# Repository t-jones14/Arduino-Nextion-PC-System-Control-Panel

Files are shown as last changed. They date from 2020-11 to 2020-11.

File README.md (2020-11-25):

<p align="center">






</p>

<p align="center">
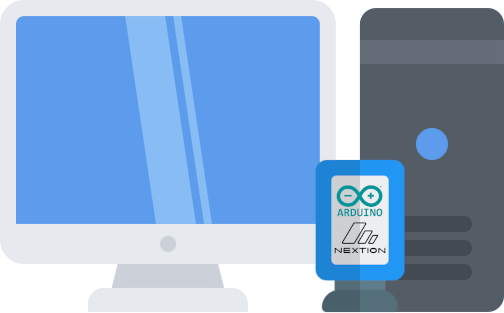
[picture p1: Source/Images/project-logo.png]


<h3 align="center">Arduino &amp; Nextion PC System Control Panel
</h3><br>
<br>
<p align="center">
An external PC system control panel built with Arduino Nano and Nextion Display<br>
<a align="center" href="https://t-jones14.github.io/Arduino-Nextion-PC-System-Control-Panel/">Explore the docs »</a><br>
<a align="center" href="https://github.com/t-jones14/Arduino-Nextion-PC-System-Control-Panel/issues">Report Bug »</a><br>
<a align="center" href="https://github.com/t-jones14/Arduino-Nextion-PC-System-Control-Panel/issues">Request Feature »</a>
</p>
</p>

<br>

## About The Project
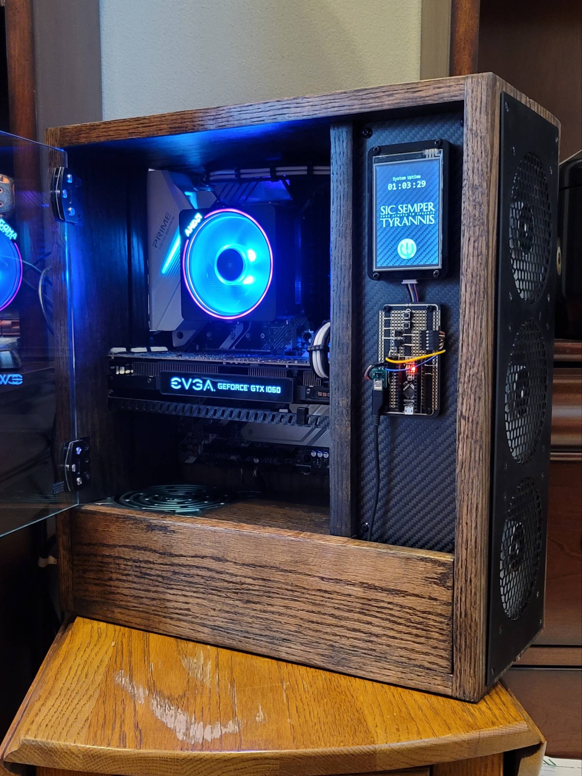
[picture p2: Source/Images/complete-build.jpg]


This project started when I decided to build a computer. Having never built one before, I decided to go all-out (kind of). I wanted it to be unique and highlight my abilities. Throughout the design and construction phase I entirely neglected to incorporate any system controls and decided to get creative. To stick with the "exposed" theme of the build the idea to incorporate a raw, yet-modern approach was born.

<a href="https://github.com/t-jones14/Arduino-Nextion-PC-System-Control-Panel">Finished Project</a>

### Built With

* Arduino Nano V3.0 (Elegoo Nano V3.0+) w/ ATmega328P: <a href="https://www.amazon.com/gp/product/B07TTN2HMQ">Amazon</a>
* Nextion Enhanced 3.5" HMI Resistive Touchscreen: <a href="https://www.amazon.com/gp/product/B08535V3KW">Amazon</a>

## Getting Started

Overall, this project is rather simple... If you're somewhat semi-technically inclined.

I highly encourage you to do your research and not take on any task you're not 110% comfortable with. As a reminder, this project is provided AS-IS with ZERO WARRANTY in any way, shape, or form. You're on your own. If you fry your motherboard, that's on you.

The saying goes: "*Measure twice, cut once.*" - Abide by it.

### Here's What You Will Need

Links to all used components included. I am not receiving any commissions if you use any of the links below.

* General Electronics Experience (Highly Recommended)
* Various Electronics Components
    * X3 Schottky Diodes: <a href="https://www.amazon.com/gp/product/B07YG8K1R9">Amazon</a>
    * X2 LED: <a href="https://www.amazon.com/gp/product/B01C19ENDM">Amazon</a>
    * X2 Pushbuttons: <a href="https://www.amazon.com/gp/product/B01CGMP9GY">Amazon</a>
    * X4 Resistors: <a href="https://www.amazon.com/gp/product/B07BKVNBH6">Amazon</a>
    * X2 BC548 Power Transistors: <a href="https://www.amazon.com/gp/product/B071P849QB">Amazon</a>
    * 2.54mm Pitch Dupont Connectors: <a href="https://www.amazon.com/gp/product/B07D91MQQ8">Amazon</a>
    * Wire Strippers: <a href="https://www.amazon.com/gp/product/B07GJFVXXD">Amazon</a>
    * Wire Crimp Tool: <a href="https://www.amazon.com/gp/product/B01CE4FAMW/">Amazon</a>
    * Soldering Iron: <a href="https://www.amazon.com/gp/product/B07SCPZJYS">Amazon</a>
    * X1 Blank Prototyping PCB: <a href="https://www.amazon.com/gp/product/B07ZYNWJ1S">Amazon</a>
    * X1 Breadboard: <a href="https://www.amazon.com/gp/product/B07DL13RZH">Amazon</a>
    * Jumper Wires: <a href="https://www.amazon.com/gp/product/B01EV70C78">Amazon</a>
* Arduino IDE: <a href="https://www.arduino.cc/en/software">Link</a>
* Nextion Editor: <a href="https://nextion.tech/nextion-editor/">Link</a>
* A motherboard with front-panel system control headers for a powerswitch, reset switch, +5V & Ground connection

## Wiring Schematic

#### A Few Notes Regarding the Schematic

1. JP1 & JP2 are to disconnect the RX/TX pins from the Arduino Nano in order to be able to upload code to the Nano without removing it from the PCB. If you leave these connected or forego the jumpers, you will not be able to upload any code to the Arduino if the Nextion is connected since the RX and TX pins are used when the board is communicating via USB.
2. J1 Pin 1 MUST be a constant +5V to power the board and display. I have my BIOS set to always supply +5 to USB so I just ran a USB from an available USB header off the motherboard.
3. J2 Pin 4 must be +5V from the motherboard ONLY when the MB is alive. I used the +5V on the System Panel Connector header for the System Warning Speaker. See below.
4. You can forego the LEDs and Pushbuttons. I opted for them for extra effect and as a backup in case the Nextion display ever stopped working before I could replace it. Better to be over-prepared than under-prepared.
5. J1 are male headers for connection to the Nextion display.
6. J2 are male headers for the wiring from the motherboard front-panel system control headers.
7. If you're using LED's from your motherboard's LED connections, ensure they are regulated. If on the off-chance they are not, you will need to integrate resistors in-series prior to the LED's.

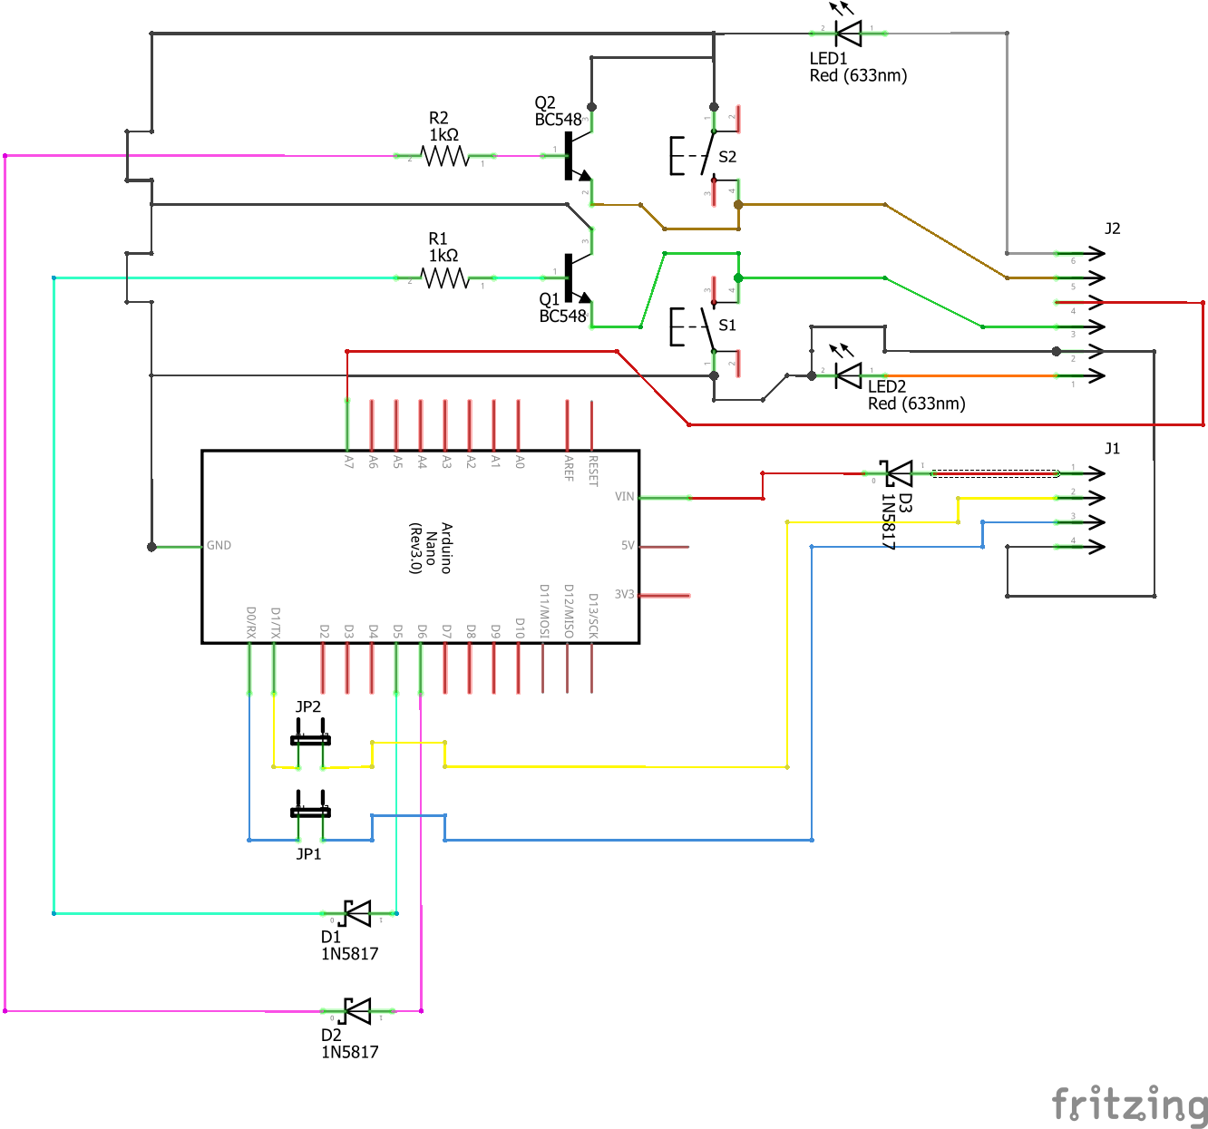
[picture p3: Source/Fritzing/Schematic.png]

Image: Wiring Schematic

For the Fritzing file <a href="https://github.com/t-jones14/Arduino-Nextion-PC-System-Control-Panel/blob/main/Source/Fritzing/Schematic.fzz">click here</a>.

## Breadboard Prototype / Bench Test

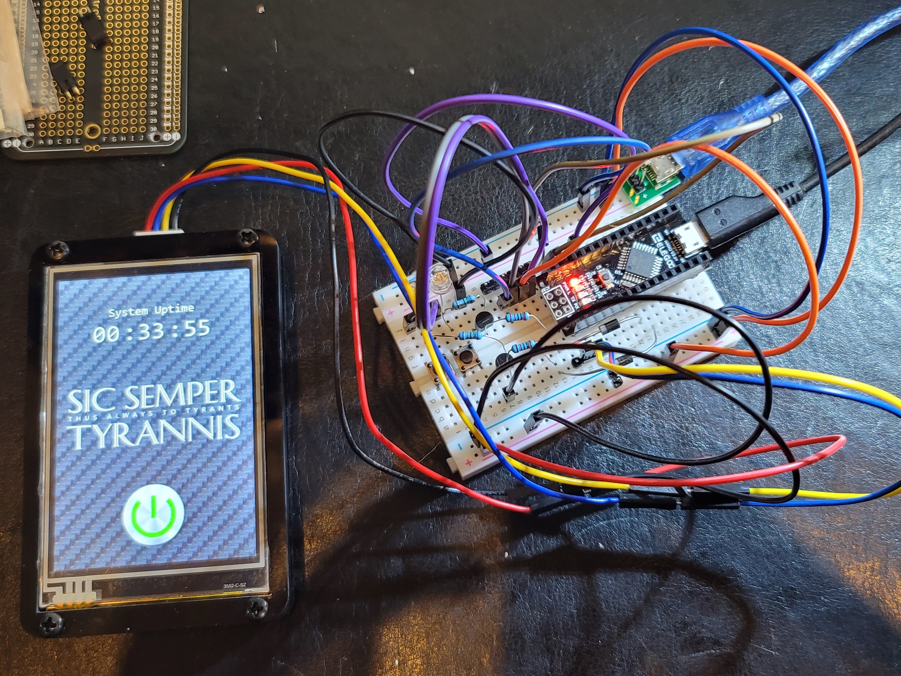
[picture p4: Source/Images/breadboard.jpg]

Image: Breadboard Prototype


Image: Final PCB Prototype

## Motherboard Wiring

Please reference your motherboard's user manual or contact your motherboard manufacturer to confirm wiring / operation. Again, this software and hardware is provided **AS-IS** with **NO WARRANTY** expressed or implied. I **am not** responsible if you fry your motherboard. Please DO NOT continue if you're not confident in your abilities. I cannot tell you how many times I confirmed details and reconfirmed before attaching any wires up to my $250 motherboard.

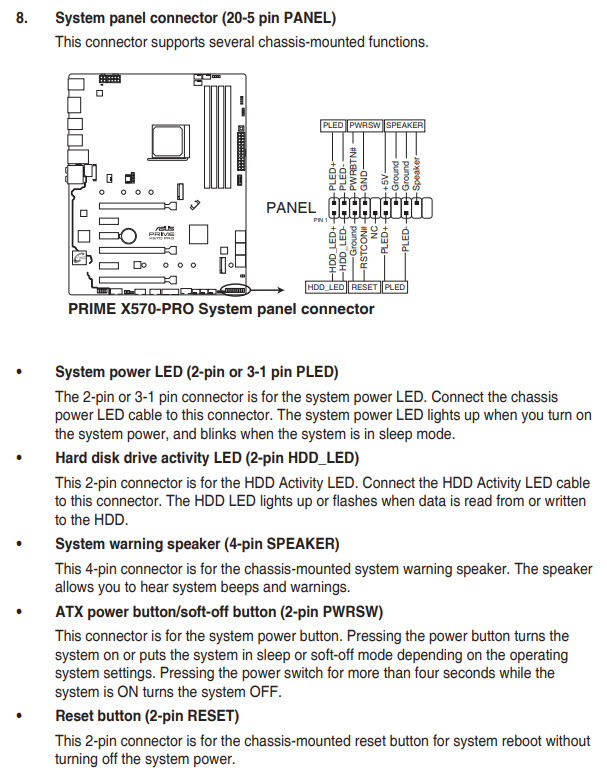
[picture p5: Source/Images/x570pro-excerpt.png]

Image: ASUS Prime X570-Pro User Manual Excerpt
Link: <a href="https://dlcdnets.asus.com/pub/ASUS/mb/SocketAM4/PRIME_X570-PRO/E17432_PRIME_X570-PRO_UM_v3_web.pdf">Asus Prime X570-Pro User Manual</a>


Image: Motherboard System Panel Connection Headers

## Roadmap

See the [open issues](https://github.com/t-jones14/Arduino-Nextion-PC-System-Control-Panel/issues) for a list of proposed features (and known issues).

## Contributing

Contributions are what make the open source community such an amazing place to be learn, inspire, and create. Any contributions you make are **greatly appreciated**.

1. Fork the Project
2. Create your Feature Branch (`git checkout -b feature/AmazingFeature`)
3. Commit your Changes (`git commit -m 'Add some AmazingFeature'`)
4. Push to the Branch (`git push origin feature/AmazingFeature`)
5. Open a Pull Request

## License

Distributed under the GNU General Public License V3.0. See `LICENSE` for more information.

## Contact

Taylor Jones - taylor@nexgendms.com

Project Link: [https://github.com/github/t-jones14/Arduino-Nextion-PC-System-Control-Panel](https://github.com/t-jones14/Arduino-Nextion-PC-System-Control-Panel)

## Acknowledgements

* [Read Me Template by othneildrew](https://github.com/othneildrew/Best-README-Template)

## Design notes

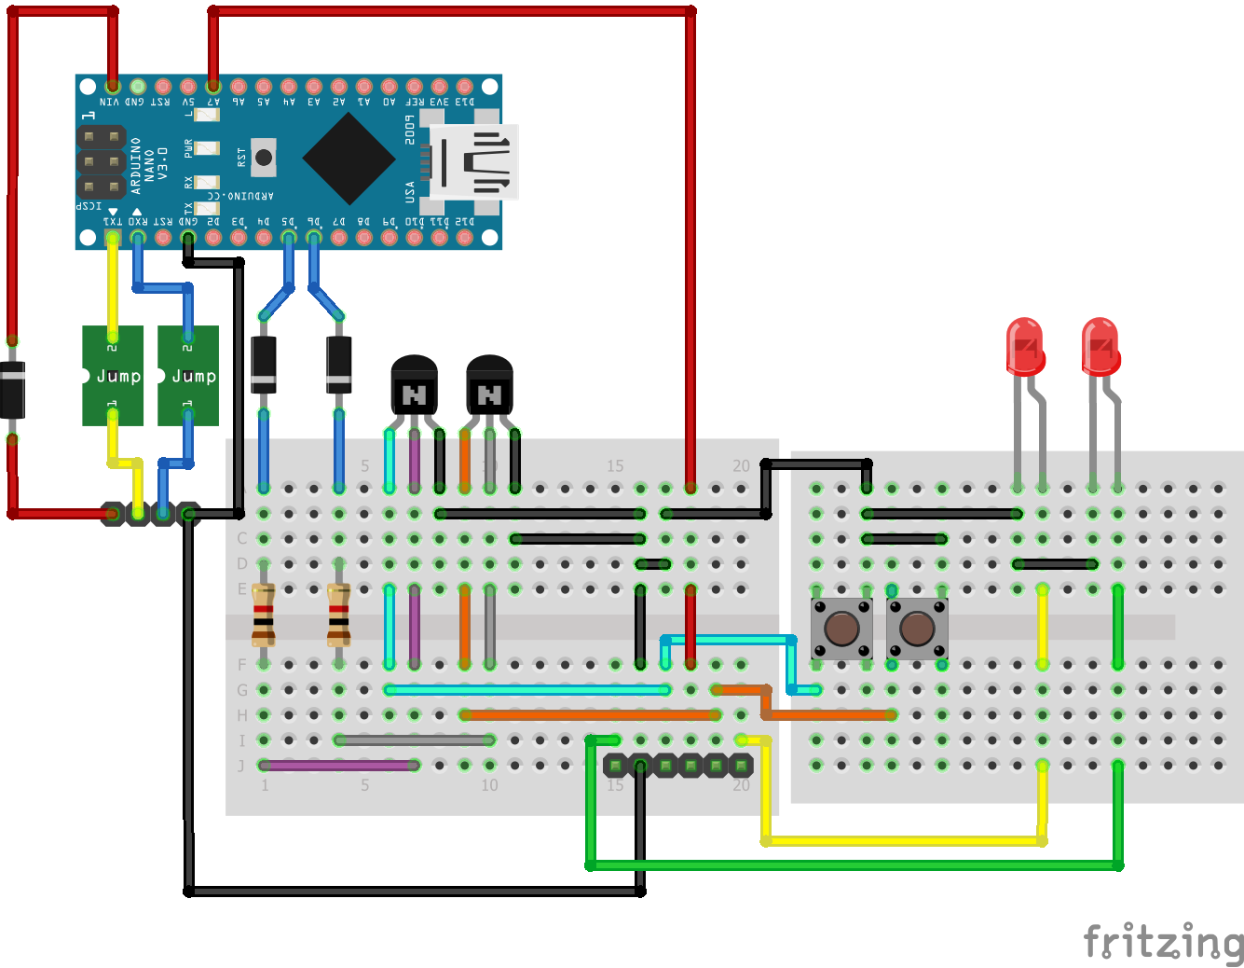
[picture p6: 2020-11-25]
Source/Fritzing/Schematic_bb.png

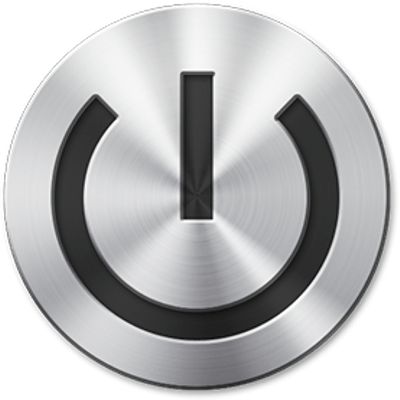
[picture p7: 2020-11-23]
Source/Images/pwrBtn-dark.png

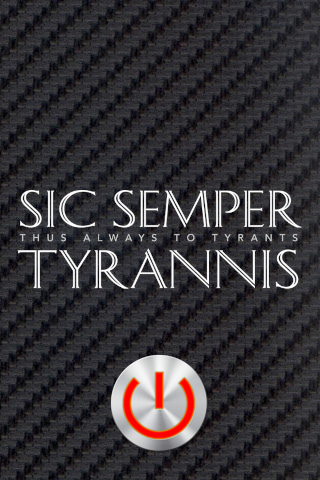
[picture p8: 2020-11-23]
Source/Images/bg-cf-sst-pwr-off.png

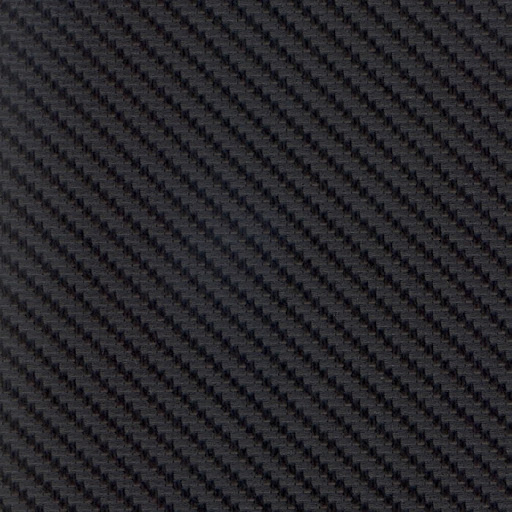
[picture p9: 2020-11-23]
Source/Images/carbonFiber.jpg

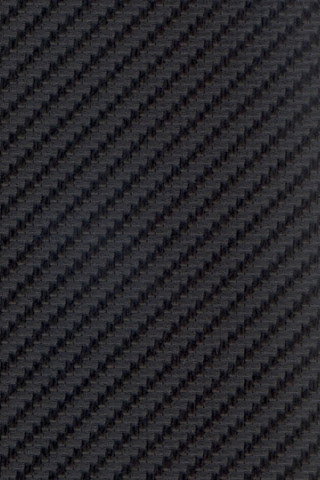
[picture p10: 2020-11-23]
Source/Images/carbonFiber-320x480.png

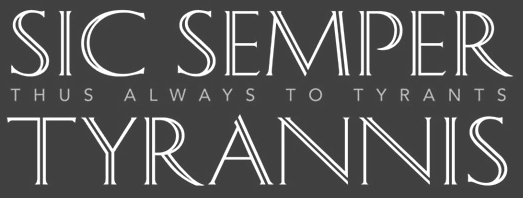
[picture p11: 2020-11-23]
Source/Images/SIC-SEMPER-TYRANNIS.png

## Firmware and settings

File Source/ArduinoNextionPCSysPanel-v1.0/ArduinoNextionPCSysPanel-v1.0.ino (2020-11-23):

/*  Arduino & Nextion PC System Control Panel
 *  Copyright (C) 2020  by Taylor Jones / www.github.com/t-jones14

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
*/

#include <EasyNextionLibrary.h> // include library
#include <trigger.h>            // include library

EasyNex myNex(Serial);          // Create an object of EasyNex class

// CUSTOMIZABLE VARIABLES
const int POWER_SW = 5;         // BJT1 - Check Schematic
const int RESET_SW = 6;         // BJT2 - Check Schematic
const int MB_CHECK = A7;        // +5V From Motherboard System Panel Connector

const int FORCE_TIME = 4000;     // Amount of time to hold POWER_SW closed to force system shutdown
// NOTE: Consult your motherboard user manual for the time required for forced shutdown.

// FIXED VARIABLES
// Do not edit these unless you know what you're doing.
// ====================================================
// State Management Variables
int mbState = 0;                  // This variable will hold the state of the motherboard. 0:Off/1:On
int interval = 1000;              // Rate (in millis) to run our custom loop

// Time Variables
unsigned long refresh_timer = millis();  // timer for refreshing Nextion's page
long currentMillis = millis();           // This will store the current time
unsigned long previousMillis = 0; // This will store the last time we looped
long sysStartTime = 0;            // This will store the time (in millis) when the MB was powered on
// TODO: long sysStopTime = 0;    // NOT IMPLEMENTED: This will store the time (in millis) when the MB was powered off last
long currentUptime = (sysStartTime - currentMillis);  // This will store our current system uptime
String rUptime = "";              // This var holds the readable uptime thats written to nextion display

//Nextion Variables to Write
String vHr = "";                  // Hours
String vMin = "";                 // Minutes
String vSec = "";                 // Seconds

// setup() runs when the Arduino is powered on or software reset (RST)
void setup() {

  myNex.begin(9600); // Begin serial communication with Nextion

  // Set the Output and Input pins
  pinMode(POWER_SW, OUTPUT);
  pinMode(RESET_SW, OUTPUT);
  pinMode(MB_CHECK, INPUT);

  // When the arduino is first powered on we need to figure out what state we need to be in.
  // We will accomplish this by first checking if the motherboard is powered on or not.
  float mbVoltage = getMbVoltage(); // get motherboard voltage via getMbVoltage() helper function

  // Now, let's get the current page Nextion is showing
  int currentPage = getCurrentPage();

  // if motherboard voltage is greater-than 1V
  if (mbVoltage > 1) {
    mbState = 1;              // set the motherboard state to 1:ON
    sysStartTime = millis();   // set the system start time
    if (currentPage != 1) {

      myNex.writeStr("page 1"); // Since motherboard is on, go to page 1
      loop();  // Now our arduino and nextion are in-sync and on the proper pages. Let's head to the loop();

    }
  } else {
    mbState = 0; // set the motherboard state to 0:OFF
    if (currentPage != 0) {
      myNex.writeStr("page 0"); // Since motherboard is off, go to page 0
      loop();  // Now our arduino and nextion are in-sync and on the proper pages. Let's head to the loop();
    }
  }

}

void loop() {

  // Our loop is pretty simple... we just need to listen for trigger events from the display
  // and write the system uptime to the display if the system is powered on.

  // lets start by checking what state we're in
  // lets get the current page just to make sure we're in-sync
  int currentPage = getCurrentPage();
  if (mbState == 1 && currentPage == 1) {
    // we're going to use a built-in "delay" so we're not sending needless writes to the nextion display
    if ((millis() - refresh_timer) > interval) {
      // since the motherboard is on and we're on page1 lets update the displayed uptime
      getUptime(); // update our time variables
      myNex.writeStr("tHr.txt", vHr); // write system hours uptime
      myNex.writeStr("tMin.txt", vMin); // write system minutes uptime
      myNex.writeStr("tSec.txt", vSec); // write system seconds uptime
      refresh_timer = millis();  // Set the timer equal to millis, create a time stamp to start over the "delay"
    }
  } else if (mbState == 1 && currentPage == 0) {

    // since motherboard is on, but we're on page0 lets get to page1
    // NOTE: currentPage!=1 is not used here because of page2 (shutdown options)
    myNex.writeStr("page 1"); // force page1

  }
  myNex.NextionListen(); // This function listens for Nextion events
}

// When the "page3 > Normal" OR "page0 > Power" option is selected
void trigger1() {

  int currentPage = getCurrentPage(); // get the current page Nextion is displaying

  // lets figure out which page we're on so we can perform the proper sequence
  if (currentPage == 0) {
    // since we're on page0 that means the system is off and we're booting it up
    sysStartTime = millis(); // set the system start time
    mbState = 1; // set mbState to 1 since we're turning on the PC
  } else if (currentPage == 2) {
    // since we're on page 2 (shutdown options)
    mbState = 0; // set mbState to 0 since we're turning off the PC
    myNex.writeStr("tHr.txt", "00"); // write system hours to 00
    myNex.writeStr("tMin.txt", "00"); // write system minutes to 00
    myNex.writeStr("tSec.txt", "00"); // write system seconds to 00
    //TO-DO:  Implement last total uptime
  }

  // trigger the switch
  digitalWrite(POWER_SW, HIGH);   // apply voltage to the BJT Base
  delay(500);                     // keep switch closed for 1/2 second
  digitalWrite(POWER_SW, LOW);    // Remove voltage from the BJT Base
}

// When the "page3 > Force" option is selected
void trigger2() {
  // trigger the switch
  digitalWrite(POWER_SW, HIGH);   // apply voltage to the BJT Base
  delay(FORCE_TIME);              // how long to hold closed for forced shutdown
  mbState = 0;                    // set mbState to 0 since we're turning off the PC
  digitalWrite(POWER_SW, LOW);    // Remove voltage from the BJT Base
}

// When the "page3 > Reset" option is selected
void trigger3() {
  // triger the switch
  digitalWrite(RESET_SW, HIGH);   // apply voltage to the BJT Base
  delay(500);                     // keep closed for 1/2 second
  digitalWrite(RESET_SW, LOW);    // Remove voltage from the BJT Base
}

// This helper function reads the voltage on the MB_CHECK pin and returns a float voltage value (X.XX)
float getMbVoltage() {
  // read the MB_CHECK pin voltage
  int sv = analogRead(MB_CHECK);

  // Convert the analog reading (which goes from 0 - 1023) to a voltage (0 - 5V)
  float mbV = sv * (5.0 / 1023.0);

  // return the value
  return mbV;
}

int getCurrentPage() {
  int pageId = myNex.currentPageId; // store the current page id eg. 0,1,2,3 etc...
  return pageId;
}

// This helper function pads our string time values with a leading zero if the number is less than 10.
String padding( int number, byte width ) {
  int currentMax = 10;
  for (byte i = 1; i < width; i++) {
    if (number < currentMax) {
      return String("0" + String(number));
    }
    currentMax *= 10;
  }
  return String(number);
}

// This helper function calculates our system uptime and puts it into a human-readable string
// Based on UPTIME by limbo at https://forum.arduino.cc/index.php?topic=8774.0
void getUptime() {
  currentUptime = (millis() - sysStartTime); // This will store our current system uptime
      long days = 0;
      long hours = 0;
      long mins = 0;
      long secs = 0;
      secs = currentUptime / 1000;          //convert milliseconds to seconds
      mins = secs / 60;                     //convert seconds to minutes
      hours = mins / 60;                    //convert minutes to hours
      days = hours / 24;                    //convert hours to days
      secs = secs - (mins * 60);            //subtract the coverted seconds to minutes in order to display 59 secs max
      mins = mins - (hours * 60);           //subtract the coverted minutes to hours in order to display 59 minutes max
      hours = hours - (days * 24);          //subtract the coverted hours to days in order to display 23 hours max
      String fHours = String(padding(hours, 2));    //format hours with leading zero if <10 and convert to string
      String fMins = String(padding(mins, 2));      //format minutes with leading zero if <10 and convert to string
      String fSecs = String(padding(secs, 2));      //format seconds with leading zero if <10 and convert to string
      //String uptime = fHours + ":" + fMins + ":" + fSecs; // Set the uptime var
      vHr = fHours;
      vMin = fMins;
      vSec = fSecs;
}

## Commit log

2020-11-23 Initial Commit
    Initial project commit
    [Schematic.fzz]
2020-11-23 Update Schematic
    Previous schematic showed transistors not connected to ground.
2020-11-25 Add files via upload
    Corrected +5V from Motherboard and +5V from USB Power
2020-11-25 Upload Breadboard Schematic
2020-11-25 Update HMI File
    Updated screen orientation for vertical mounting (180).
2020-11-25 Updated Schemantic
    Wiring missing on J1 to D3.

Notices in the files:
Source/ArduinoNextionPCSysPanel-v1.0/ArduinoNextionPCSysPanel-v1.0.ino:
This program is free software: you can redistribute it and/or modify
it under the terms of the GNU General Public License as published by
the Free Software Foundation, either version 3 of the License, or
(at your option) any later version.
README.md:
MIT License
